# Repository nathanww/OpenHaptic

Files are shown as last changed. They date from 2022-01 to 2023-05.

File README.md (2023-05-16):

# OpenHaptic
 Welcome! OpenHaptic is a system for interfacing with the sense of touch in rich ways.
Some things you can do with OpenHaptic:
* Build [Sensory augmentation](https://en.wikipedia.org/wiki/Sensory_substitution) systems that let you sense radar signals, infrared, ultrasound, etc
* Use vibratory stimuli to [control the autonomic nervous system](https://www.healio.com/news/rheumatology/20190417/vibration-stimulation-of-external-ear-alleviates-inflammation-in-ra)
* Build an unintrusive notification systems
* Provide biofeedback/neurofeedback
* Make haptic interfaces for AR, VR, and video games

# Hardware build
The OpenHaptic hardware consists of a [ESP32 Feather](https://www.adafruit.com/product/3405) connected to 3 vibration motors and a battery. The parts used in my build were:

The specific part numbers we used were:
* [1 ESP32 Feather](https://www.adafruit.com/product/3405)
* [3 DZS electric vibration motors](https://www.amazon.com/gp/product/B07PHRX7QH)
* [3 Fairchild 2N7000 MOSFETS](https://www.amazon.com/gp/product/B07PHRX7QH)
* [1 Adafruit 2500mAh lipo battery]([https://www.adafruit.com/product/3898](https://www.adafruit.com/product/328)) *

Assembly is fairly simple; each MOSFET is used to drive a motor (make sure that the MOSFET is placed in the low side of the motor, the current path should be battery -> motor -> MOSFET source -> MOSFET drain -> ground). The battery is plugged into the Feather's battery terminals; an onboard circuit will automatically control charging and discharging

*2500 mAh is a good sized battery that gives you a full day of charge for most applications, however this battery is available in multiple sizes--you can get a larger one, or a smaller one, though at least 500 mAH is probably a good benchmark for at least a few hours of runtime.

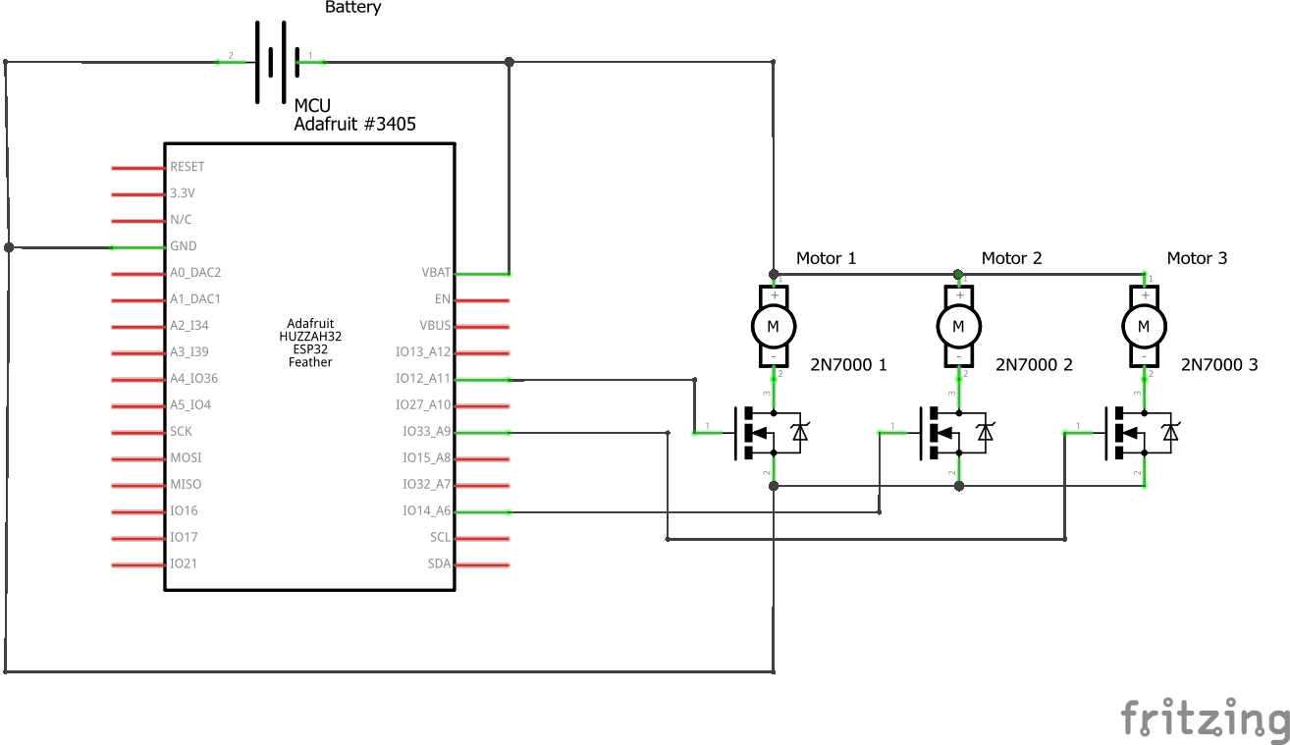
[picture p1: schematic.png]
Circuit schematic

# Software installation

1. Install MicroPython on your ESP32 feather, as shown [here](https://docs.micropython.org/en/latest/esp32/tutorial/intro.html)
2. Download the main.py file and use [Thonny](https://thonny.org/) to save it on the Feather board.

All of the critical software is now installed, but your OpenHaptic won't do anything until you load an app on it. The easiest way to do that is using our [Android app](https://play.google.com/store/apps/details?id=appinventor.ai_nathanwhitmore2020.hapticProgrammer) which will let you load Python code on the board. A few demo programs are included with the Android app for you to load.

Once code is loaded, it will run immediately, and every time the board starts up it will wait 30 seconds and then run the last loaded program
# Use
The Openhaptic Programmer app will you you install and remove programs and communicate with the device.

You can also toggle programs on and off by pressing the reset button on the board itself. Each time you press it the board will switch between "program running" and "idle" states
# Programming
The OpenHaptic board will run any Micropython program you load on it; you can do anything one could do in micropython. There are also some convenience functions that simplify building apps, see [here](https://github.com/nathanww/OpenHaptic/blob/main/api.md) for details

# Communicating with other devices
The ESP32 device has a Bluetooth/Wifi radio, and OpenHaptic [includes some APIs](https://github.com/nathanww/OpenHaptic/blob/main/api.md) for communicating with another device over Bluetooth. 
It is also entirely possible to ignore the API and just use custom Micropython code for communication.

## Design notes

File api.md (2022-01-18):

# OpenHaptic API
There are a few functions included with OpenHaptic to simplify building applications. Using the API is not required; you can also write Micropython code that accesses all the hardware directly.

# Vibration functions

**vibePattern(intensity, timing, loop=0,pwmFreq=1000)**

Executes a vibration pattern on the three vibration motors

Vibration pattern are defined by two lists, one listing the vibration intensity(0-100 and the other vibration duration(in seconds). Each pattern can consist of multiple segments with different intensities. For example, the pattern
intensity=[0,100,0,100]
timing=[0.5,0.5,0.5,0.5] pulses the motor on once a second

*Arguments*

intensity--a list of three lists, each of which contains the intensity sequence for one motor

timing--a list containing the duration of each segment. The same timing is used for all motors.

loop--the number of times to loop the sequence

pwmFreq--frequency of the PWM drivers. The default (1000) is almost always good, but can be adjusted

**[intensity,timing]=waveSynth(freq,power,duration=1,waveform="sine",lowcut=0,highcut=100,stepSize=0.01,phaseOffset=[0,0,0])**

Generates intensity and timing lists to produce a specified waveform. This function generates three waves at once (one for each motor)

*Arguments*

freq--List of 3 frequencies in Hertz, corresponding to motors 1-3

power--List of three peak intensities, from 0 to 100, corresponding to motors 1-3

duration--duration in seconds

waveform--either "sine" or "square"

lowcut--minimum intensity for any point

highcut--maximum intensity for any point

stepSize--how long does each time point last in seconds. This can be adjusted to trade off resolution and memory use

phaseOffset--Lets you shift the phase of the wave. By default, waves are generated as wave=sine(x) from x=0 to x=6.28. However, you can override this by setting this variable for each motor--for instance if a motor's phase offset is set to 1, the wave will be generated from points 1 to 7.28.

*Outputs*

intensity--intensity list for in the format used by vibePattern. This is a list of three lists, each one of which contains the sequence for a particular motor.

timing--timing list in the format used by vibepattern

**wave=combineWaves(wave1,wave2,weight=1.0)**

Creates a composite wave by blending two separate waveforms. This function deals with intensity lists in vibePattern format

*Arguments*

wave1--intensity list of all the segments for the first wave

wave2--intensity list of all the segments for the second

weight--relative weights of the first and second wave. Values greater than 1 weight the second wave more highly, values less than 1 weight the first wave more highly.

*Outputs*

wave--the intensity list for the combined wave.

**wave=modulate(wave1,wave2)**

Uses wave 2 to scale wave 1. the resulting wave at time x is wave1[x]\*(wave2[x]/100)

*Arguments*

wave1--intensity list of all the segments for the first wave

wave2--intensity list of all the segments for the second

*Outputs*

wave--the intensity list for the resulting wave.

# Communication protocol
OpenHaptic uses the Nordic UART BLE service for loading programs.  The OpenHaptic Programmer app also uses this service to create an interactive shell for users to interact with the device. Alterantively, the connection can be used to send data between a app running on OpenHaptic and a companion device. Programs can also accsess the Bluetooth/wifi hardware directly for other types of connections.

*Using the OpenHaptic shell (easiest method)*

First, check that a connection exists by checking that **ble.isConnected** is true.

If it is, you can send data to be displayed to the user by calling

**ble.send(data)**

Where data is an UTF-8 string to be displayed in the OpenHaptic Programmer application

Data received from the shell is stored as a string in the **lastData** variable. Another variable, **lastDataTime**, keeps the time.time() timestamp of when the last data transmission ended.

*Connecting your own apps*
If you want to send data without using the shell, your app must first make a BLE GATT connection to the OpenHaptic device

Device name: OpenHaptic

Service UUID: '6E400001-B5A3-F393-E0A9-E50E24DCCA9E'

OpenHaptic's "receive" GATT attribute: 6E400002-B5A3-F393-E0A9-E50E24DCCA9E

OpenHaptic's "transmit" attribute: 6E400003-B5A3-F393-E0A9-E50E24DCCA9E

*Message formats*
To send a message to the device, write it to the GATT receive attribute. The message should be an UTF-8 string ending in "ENDMSG"

Messages sent by OpenHaptic are also strings terminated with "ENDMSG". 

The OpenHaptic device attempts to send status messages when connected: These are prefaced by "ST:" and consist of the current battery voltage, a comma, and the current program status (0=not running program, 1=running program)

Messages prefaced with "PROG:" are commands to overwrite the current program with the data that comes afterwards.

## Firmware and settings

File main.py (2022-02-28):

import machine 
from machine import Pin, Timer,ADC,PWM
import sys
from time import sleep_ms
import ubluetooth
import esp32
from esp32 import raw_temperature
import _thread
import time
import math
runSavedCode=True #can be set to false to prevent saved code from interrupting the loading of a new program
runProgram=True #keep the program running in a loop
programStatus=0
lastData=""
lastDataTime=-1
import math
def waveSynth(freq,power,duration=1,waveform="sine",lowcut=0,highcut=100, phaseOffset=[0,0,0],stepSize=0.2):
    powerCheck=[len(freq), len(power)]
    if max(powerCheck) != min(powerCheck):
        return -1 #arrays are not the right size
    else:
        while len(phaseOffset) < len(freq):
            phaseOffset.append(0)
        motors=[] 
        totalPoints=(6.28*duration)/stepSize
        timing=[]
        for motor in range(0,len(freq)):
            #generate a sine wave
            temp=[]
            x=0 
            while (round(x,2) < (6.28*duration)):
                #set up the timing array
                if motor == 0:
                    timing.append(duration/totalPoints)
                tempVal=(math.sin((x+phaseOffset[motor])*freq[motor])+1)*power[motor]/2 #scale in the x domain (to control frequency) and in the y domain to control how the power is mpped to motor power
                if waveform == "square": #if user asked for a square wave then threshold the sine wave
                    if (tempVal > 50):
                        tempVal=100
                    else:
                        tempVal=0
                if tempVal < lowcut:
                    tempVal=lowcut
                if tempVal > highcut:
                    tempVal=highcut
                temp.append(int(tempVal))
                x=x+stepSize
            motors.append(temp)
        return [motors,timing]
def combineWaves(wave1,wave2,weight=1.0):
    
    """combines two waveforms (with equal length) toghether.
    
    Arguments:
    wave1 -- list containing points in the first waveform
    wave2 -- list contianing points in the second waveform
    weight -- how much to weight the second waveform relative to the first. 1.0 is equal weight
    """
    newWave=[]
    if len(wave1) != len(wave2):
        print("Error, the two waves are not equal length")
        return -1
    else:
        for i in range(0,len(wave1)):
            #We combine add the two waves but scale the second by weight. Then we scale them so that the overall sum is the same as the original waveform
            temp=((wave1[i]/2)+((wave2[i]/2)*weight))
            #find the amplitude of the new point compared to the old point, and use this to rescale the wave so that the amplitude doesn't change
            scale=(1+weight)/2 
            newWave.append(int(temp/scale))
            
    return newWave
def modulate(wave1,wave2):
    
    """modulates wave1, computing wave=wave1*(wave2/100)
    
    Arguments:
    wave1 -- list containing points in the first waveform
    wave2 -- list contianing points in the second waveform
    """
    newWave=[]
    if len(wave1) != len(wave2):
        print("Error, the two waves are not equal length")
        return -1
    else:
        for i in range(0,len(wave1)):
            newWave.append(int(wave1[i]*(wave2[i]/100))) 
            
    return newWave

def heatMotors(duration): #experimental, tries to create heat but not motion on the vibration motors
    print("initial temp:"+str(raw_temperature())) 
    pin1=PWM(Pin(12,Pin.OUT),freq=10000000,duty=700) 
    pin2=PWM(Pin(14,Pin.OUT),freq=10000000,duty=700)
    pin3=PWM(Pin(33,Pin.OUT),freq=10000000,duty=700)
    time.sleep(duration) 
    pin1.deinit()
    pin2.deinit()
    pin3.deinit()
    print("final temp:"+str(raw_temperature()))
    
def chirpMotors(): #creates a breif motor chirp as confirmation
    pin1=PWM(Pin(12,Pin.OUT),freq=1000,duty=500) 
    pin2=PWM(Pin(14,Pin.OUT),freq=1000,duty=500)
    pin3=PWM(Pin(33,Pin.OUT),freq=1000,duty=500)
    time.sleep(0.1)
    pin1.duty(0)
    pin2.duty(0)
    pin3.duty(0)
    time.sleep(0.1)
    pin1.duty(500)
    pin2.duty(500)
    pin3.duty(500)
    time.sleep(0.1)
    pin1.deinit()
    pin2.deinit()
    pin3.deinit()
    
def vibePattern(motorPower,timing, loop=0,pwmFreq=1000): #execute a custom vibration pattern
   #the current PWM system has some weird behavior (I think a bug) so we are doing this custom bitbang pwm for now
    if len(motorPower) == 3: 
        powerCheck=[len(motorPower[0]), len(motorPower[1]),len(motorPower[2]),len(timing)]
        if max(powerCheck) == min(powerCheck): #check to make sure the lists are all the right length
            numSegments=len(motorPower[0])
            totalLoops=loop
            pin1=PWM(Pin(12,Pin.OUT),freq=pwmFreq,duty=0) 
            pin2=PWM(Pin(14,Pin.OUT),freq=pwmFreq,duty=0)
            pin3=PWM(Pin(33,Pin.OUT),freq=pwmFreq,duty=0)
            while totalLoops >= 0:
                totalLoops=totalLoops-1
                
                for segment in range(0,numSegments):
                    pin1.duty(motorPower[0][segment]*10)
                    pin2.duty(motorPower[1][segment]*10)
                    pin3.duty(motorPower[2][segment]*10)
                    time.sleep(timing[segment])
            pin1.deinit() 
            pin2.deinit()
            pin3.deinit() 
            return True
        else:
            print("Motor sequences don't agree")
            return -1
    else:
        print("Wrong number of motor sequences")
        return -2
    
    
def runProgramFromStorage():
    global programStatus
    print("Attempting to run program")
    if runSavedCode: 
        progFile=open("program.py")
        program=progFile.read() 
        progFile.flush()
        progFile.close()
        print(program)
        
        while runProgram:
            exec(program,globals(),locals())
        programStatus=2
        

def handleMessage(message):
    global lastData
    global lastDataTime 
    if "PROG:" in message:
        print("Loading new program...")
        program=message.replace("ENDMSG","").replace("PROG:","")
        print("Program")
        print(program)
        progFile=open("program.py",'w')
        progFile.write(program)
        progFile.flush()
        progFile.close()
        chirpMotors()
        machine.reset() 
    else:
        lastData=message
        lastDataTime=time.time()
        

class BLE():
 
    
    def __init__(self, name):
        self.isConnected=False
        self.name = name
        self.ble = ubluetooth.BLE()
        self.ble.active(True)

        
        self.disconnected()
        self.ble.irq(self.ble_irq)
        self.register()
        self.advertiser()
        self.messageBuffer=""

    
    def connected(self):
        self.isConnected=True
        


    def disconnected(self):
        self.isConnected=False
        
    

    def ble_irq(self, event, data):
        global messageBuffer
        if event == 1:
            '''Central connected'''
            self.connected()
    
        elif event == 2:
            '''Central disconnected'''
            self.register()
            self.advertiser()
            self.disconnected()
        
        elif event == 3:
            '''New message received'''
            global runSavedCode         
            runSavedCode=False
            buffer = self.ble.gatts_read(self.rx)
            message = buffer.decode('UTF-8')[:-1]
            self.messageBuffer=self.messageBuffer+message
            print(str(len(self.messageBuffer)))
            if ("ENDMSG") in self.messageBuffer:
                print(self.messageBuffer)
                handleMessage(self.messageBuffer)
                self.messageBuffer=""
                

            
    def register(self):
        
        # Nordic UART Service (NUS)
        NUS_UUID = '6E400001-B5A3-F393-E0A9-E50E24DCCA9E'
        RX_UUID = '6E400002-B5A3-F393-E0A9-E50E24DCCA9E'
        TX_UUID = '6E400003-B5A3-F393-E0A9-E50E24DCCA9E'
            
        BLE_NUS = ubluetooth.UUID(NUS_UUID)
        BLE_RX = (ubluetooth.UUID(RX_UUID), ubluetooth.FLAG_WRITE)
        BLE_TX = (ubluetooth.UUID(TX_UUID), ubluetooth.FLAG_NOTIFY)
            
        BLE_UART = (BLE_NUS, (BLE_TX, BLE_RX,))
        SERVICES = (BLE_UART, )
        ((self.tx, self.rx,), ) = self.ble.gatts_register_services(SERVICES)

    def send(self,data): #format the data for transmission to the companion app
        MTU=5 
        temp=""
        data=data+"ENDMSG"
        for char in data:
            if len(temp) <= MTU:
                temp=temp+char
            else:
                self.sendll(temp)
                temp=char
        self.sendll(temp) 
    def sendll(self, data): #low level send, doesn't check the data size etc
        self.ble.gatts_notify(0, self.tx, data)


    def advertiser(self):
        name = bytes(self.name, 'UTF-8')
        self.ble.gap_advertise(100, bytearray('\x02\x01\x02') + bytearray((len(name) + 1, 0x09)) + name)
        
# test
p12=Pin(12,Pin.OUT);
p12.value(False)
p14=Pin(14,Pin.OUT);
p14.value(False)
p33=Pin(33,Pin.OUT);
p33.value(False)
#toggle the program on or off
spEnabled=True
if (machine.reset_cause() ==1): #this means it's a poweron reset, i.e. the user pressed the reset button and we should toggle whether the program runs
    try:
        rebootFile=open("runProgram.txt",'r')
        result=rebootFile.read()
        rebootFile.close()
        rebootFile=open("runProgram.txt",'w')
        print(result)
        if "true" in result:
            spEnabled=True
            print("Prog enabled")
            rebootFile.write("false")
        else:
            spEnabled=False
            print("Prog disabled")

            chirpMotors()
            rebootFile.write("true")
        rebootFile.flush()
        rebootFile.close()
    except Exception:
        print("Error checking reboot status")
        rebootFile=open("runProgram.txt",'w')
        rebootFile.write("true")
        rebootFile.flush()
        rebootFile.close()

    

ble = BLE("OpenHaptic")
batteryVoltage=ADC(Pin(35)) 
batteryVoltage.atten(ADC.ATTN_11DB) #full range
if(spEnabled):
    _thread.start_new_thread(runProgramFromStorage, ()) #run the stored program
while True:
    if ble.isConnected: #if we have a connection, send a status message every couple of seconds
        try:
            print("sending status")
            ble.send("ST:"+str(round((batteryVoltage.read()/4095)*6.6,2))+":"+str(programStatus))
        except Exception: #this can break due to interference by a program
            pass
    time.sleep(2)
        

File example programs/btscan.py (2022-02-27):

# This program converts Bluetooth beacons into tactile sequences
#Code based on the tutorial at https://github.com/micropython/micropython/blob/master/examples/bluetooth/ble_simple_central.py
# NOTICE: You will need to press the reset button on the board to switch from this to a different program

import bluetooth
import random
import struct
import time
import micropython
import random
import machine

from micropython import const
_IRQ_SCAN_RESULT = const(5)

fired=False
wdt=machine.WDT(timeout=10000)
def seqFromAddr(addr, rssi):
    seq=[]
    random.seed(addr)
    global fired
   
    for i in range(0,5):
        motorVal=random.choice([12,14,33]) #specifies what motor this is attached to
        self._ble.gap_scan(90000000, 30000, 3000)



def runscan():
    time.sleep(5)
    print("running")
    global fired
    while True:
        ble = bluetooth.BLE()
        central = BLESimpleCentral(ble)
        central.scan(callback=None)
        print("scan")
        while (not fired):
          time.sleep(0.1)
          wdt.feed()
        fired=False
        p14 = machine.Pin(14)
        p14.init(p14.IN,p14.PULL_DOWN)
        machine.lightsleep(2000)

     

   


if __name__ == "__main__":
  stopVibe=machine.Pin(14)
  pwmOut=machine.PWM(stopVibe)
  pwmOut.duty(0)
  runscan()

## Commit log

2021-12-23 add btscan and error handling for code
    [btscan.py, main.py]
2021-12-29 start vibration handler script
    [main.py]
2021-12-29 custom pwm frequency
2021-12-30 use bitbanged PWM instead of regular (due to bugs with PWM driver)
    [main.py]
2021-12-30 fix issue where time was in seconds not milliseconds
    [main.py]
2022-01-01 grab latest version from device
2022-01-02 Fix incorrect pin assignment for motor 3
    [main.py]
2022-01-03 Update Android app with correct motor numbers
2022-01-03 Add schematics
    [schematic.fzz]
2022-01-11 Update device bluetooth name
2022-01-11 send program errors to shell
    [main.py]
2022-01-15 Make system auto-reset when new program is loaded
    [main.py]
2022-01-15 Experimental motor heating mode
2022-01-15 Fix frequency synthesizer to use correct frequencies
    [main.py]
2022-01-16 Use ESP32 PWM peripherals (debugged) instead of our hacked together one
2022-01-17 Add motor chirp when program loads
2022-01-17 Fix bug where timing array could be the wrong length
    [main.py]
2022-01-17 Fix bug with incorrect frequency being generated in waveSynth
    [main.py]
2022-01-17 Configurable PWM frequency
2022-01-17 No pause on reset if the reset was caused by program loading
    [main.py]
2022-01-18 Fix disconnected parts in schematic
    [schematic.fzz]
2022-02-02 Fix bug in program exception handling
    [main.py]
2022-02-27 Reset button toggles program on or off
2022-02-27 add watchdog timer for better stability
    [btscan.py]
2023-05-16 Update battery recommendation
